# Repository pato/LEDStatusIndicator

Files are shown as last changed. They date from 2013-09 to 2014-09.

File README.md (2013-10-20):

LEDStatusIndicator
==================

Handy device that you can use to inform people outside your dorm on whether you are available, working, sleeping, or in need of solitude

First Protype
-------------
The first prototype was just a breadboard with four LEDs. There was no way of changing color besides manually using a jump cable to power them.
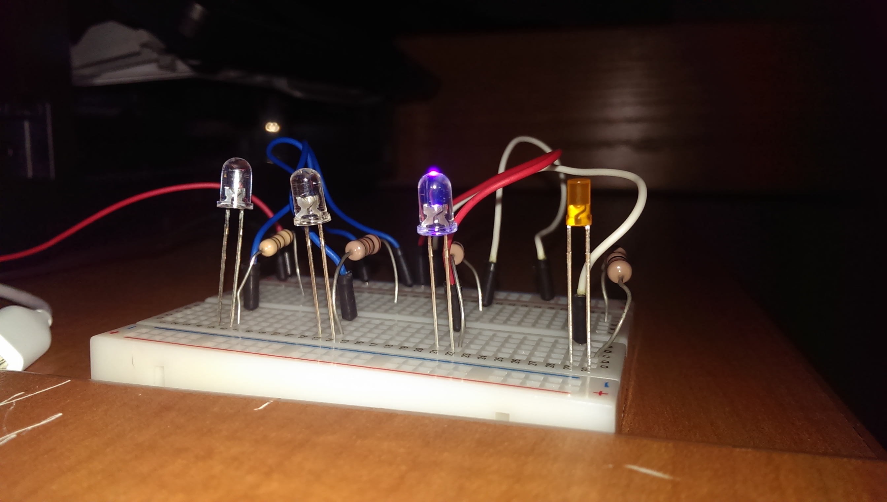
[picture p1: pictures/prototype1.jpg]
first prototype


Second Protype
--------------
The second prototype did not use a breadboard, instead I soldered the cables to the resistors to the LEDs. The anodes are all soldered together and the cathod so the LEDs are toggled by manually providing power to the desired LED.
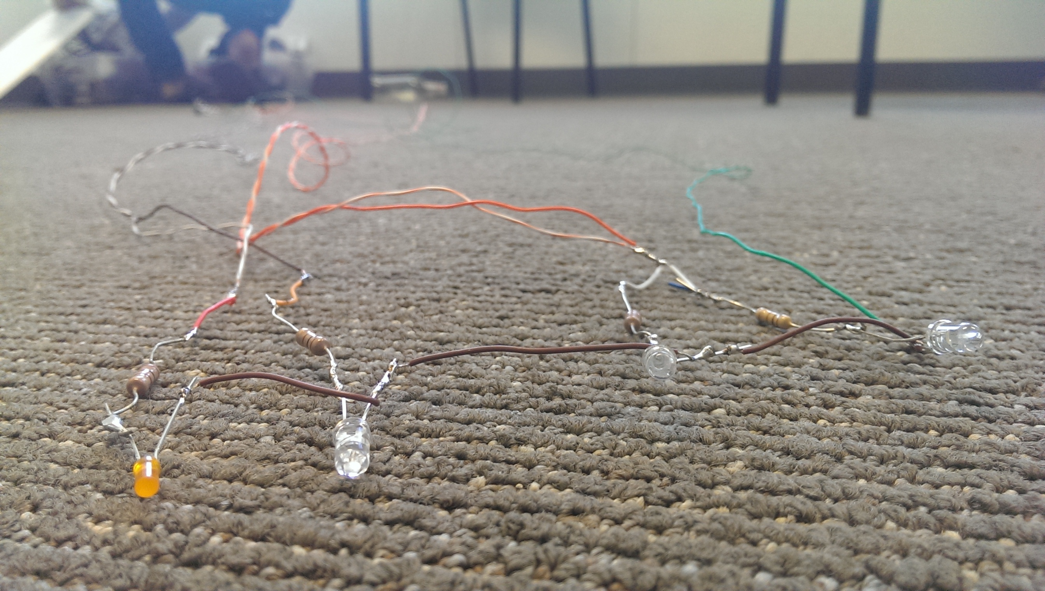
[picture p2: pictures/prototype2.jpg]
second prototype


Third Prototype
---------------
The third prototype was housed in a cardboard box, the cables to power the LEDs would go over and around the door to the inside of the room where I could control which lights turn on.
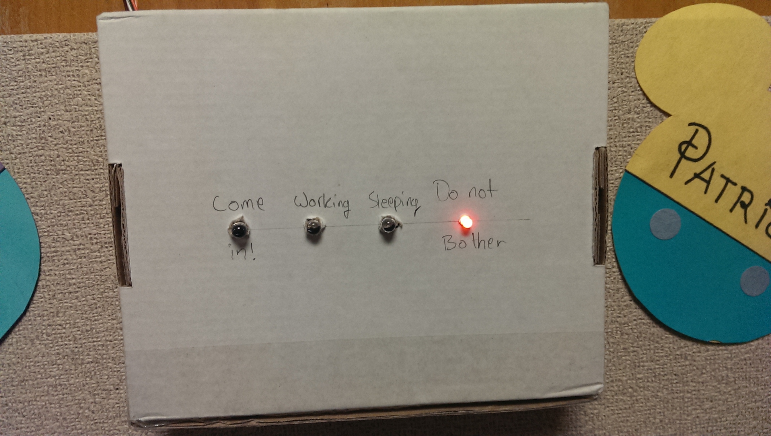
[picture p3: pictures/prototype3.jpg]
third prototype


Fourth Prototype
----------------
The fourth prototype uses an ATMega168, a push button, and an RGB LED. The button iterates through the various preset colors on the LED.
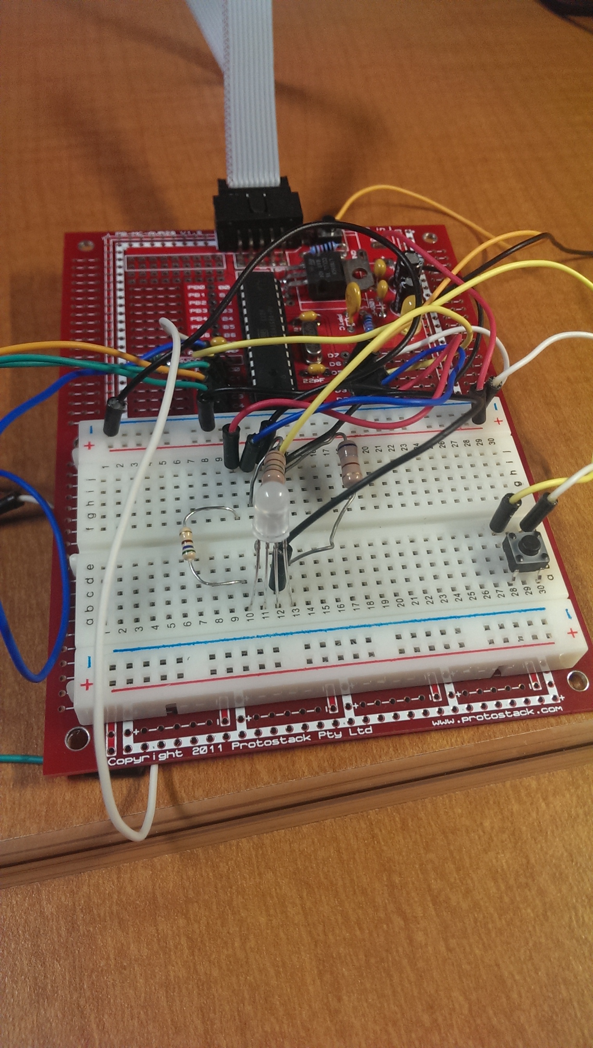
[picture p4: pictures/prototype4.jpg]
fourth prototype

This is how it looks on the other side of the door.
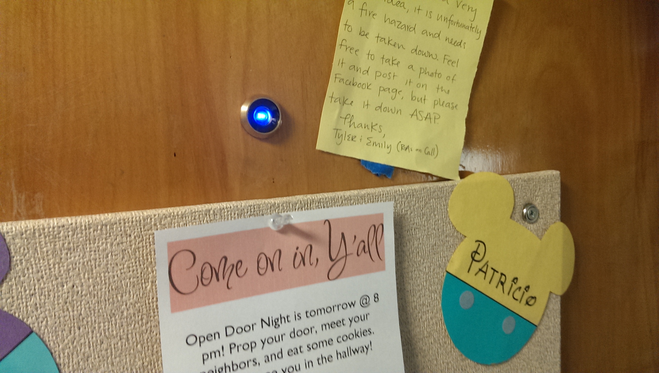
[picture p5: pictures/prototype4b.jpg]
fourth prototype


Fifth Prototype
---------------
The goal of the fifth protype was to reduce parts, size, and costs, as well as make it battery powered. We used an ATTiny45, a capacitor, four resistors, a push button, jumper cables, and RGB LED.
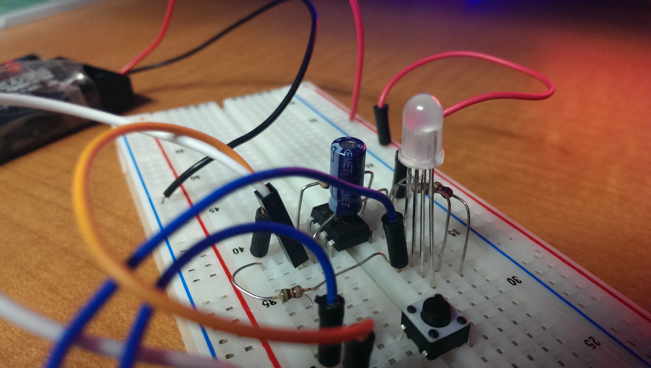
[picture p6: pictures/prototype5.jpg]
fifth prototype

In order to make it battery powered, we drastically reduced the frequence of the internal oscillator as well as made the LED pulse at interval instead of constnatly on.

First Beta
----------
The PCB boards from our friends at Oshpark! (PS: They're awesome!)
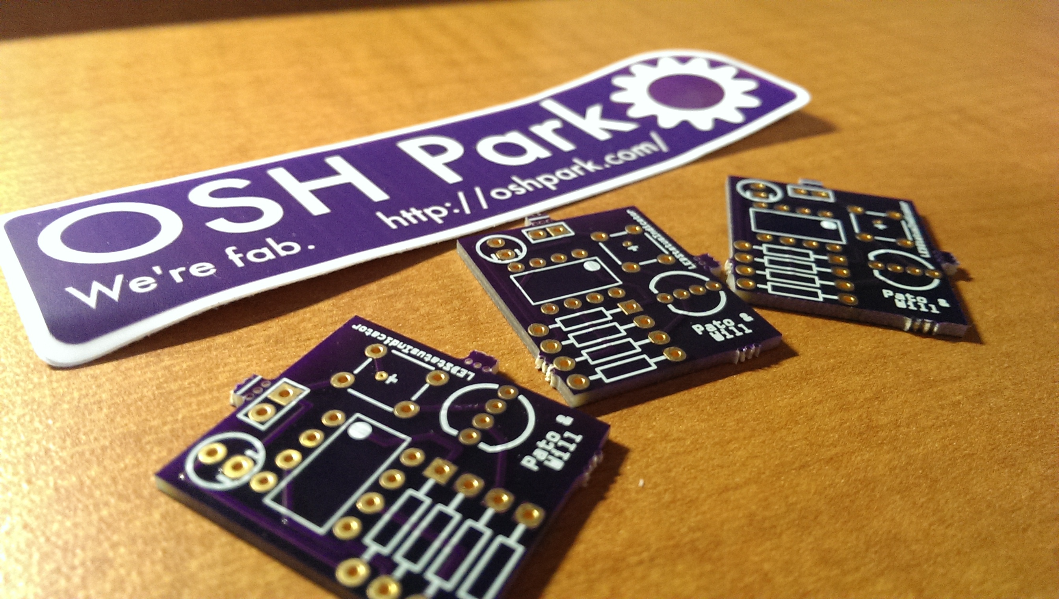
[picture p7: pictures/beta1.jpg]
first beta


From the backside
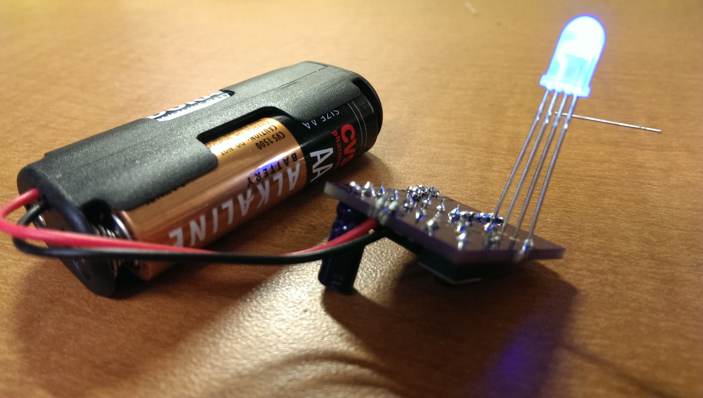
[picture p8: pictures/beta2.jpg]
first beta


From the front side
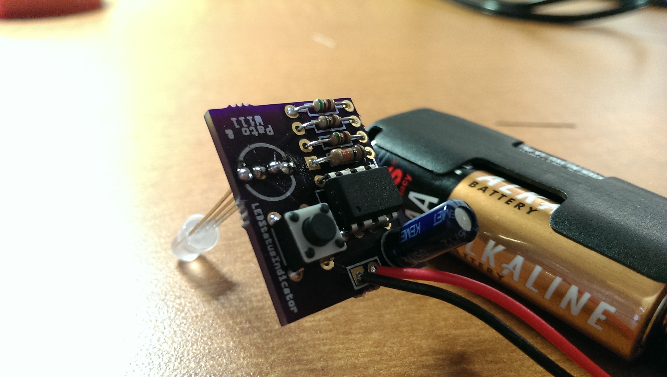
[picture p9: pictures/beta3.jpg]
first beta


Here's how it looks mounted on the door!
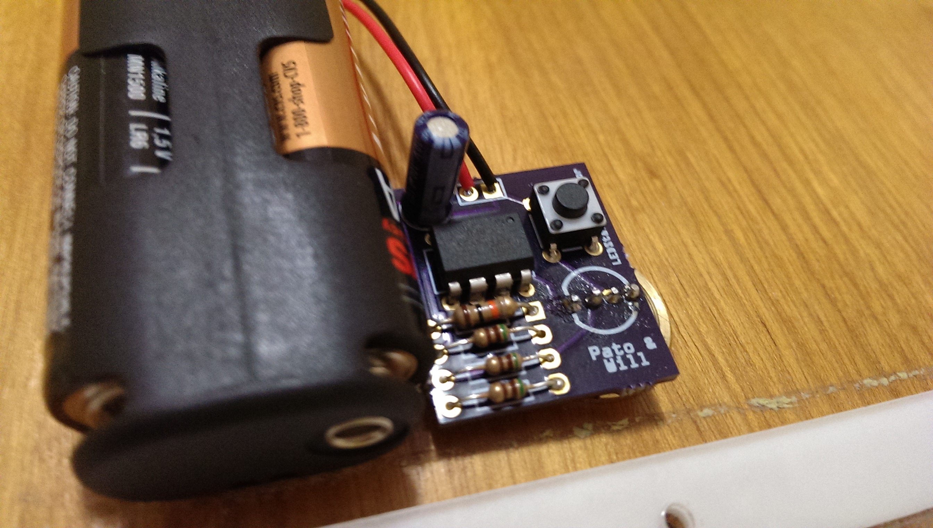
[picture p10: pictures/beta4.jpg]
first beta


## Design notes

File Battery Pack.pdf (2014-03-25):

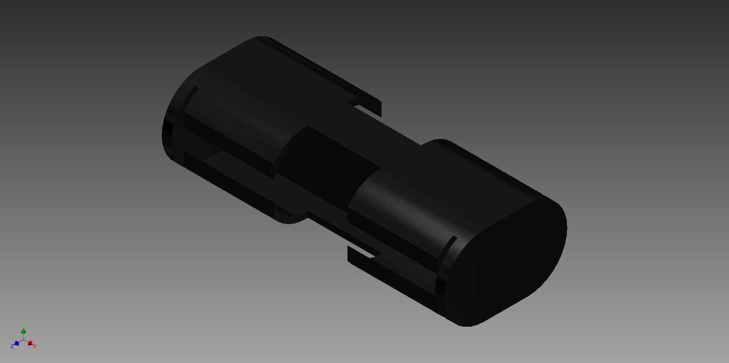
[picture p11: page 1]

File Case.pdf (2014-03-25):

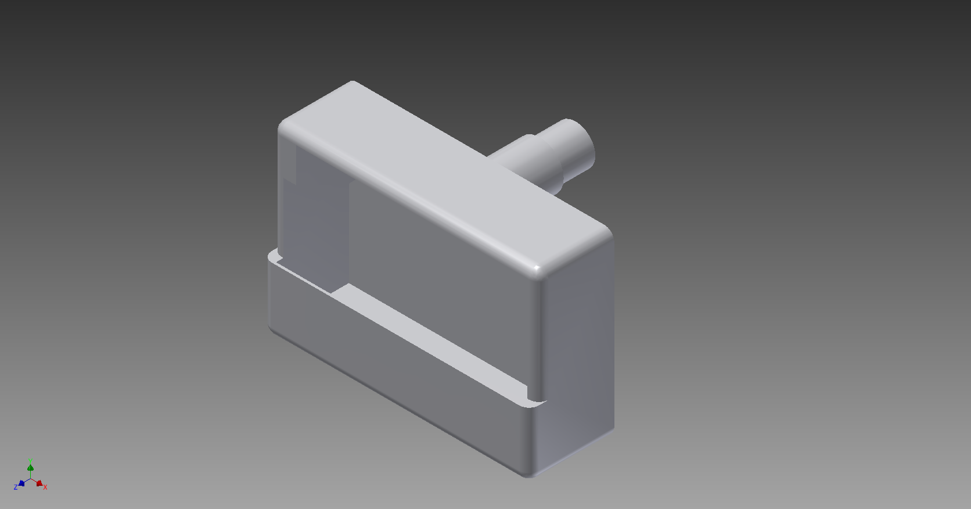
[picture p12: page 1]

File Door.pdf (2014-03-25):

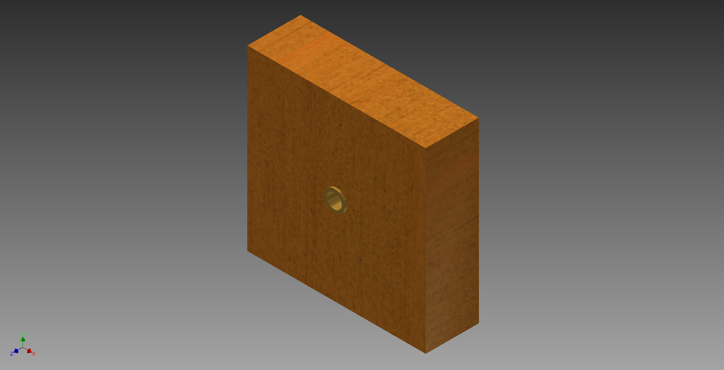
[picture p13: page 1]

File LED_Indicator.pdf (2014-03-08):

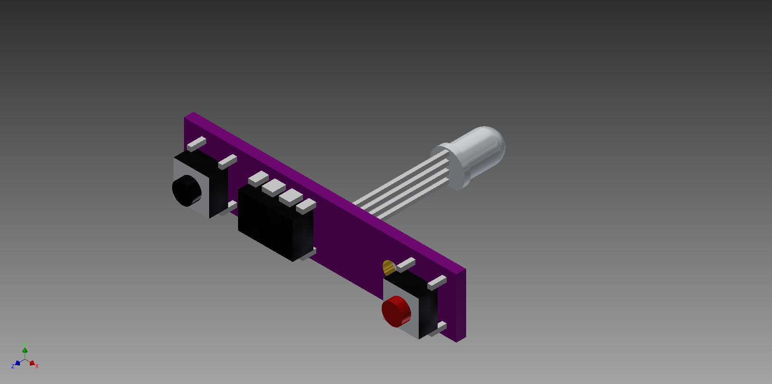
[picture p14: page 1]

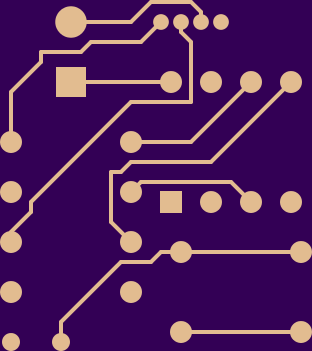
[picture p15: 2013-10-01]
PCB/render/large_i4.png

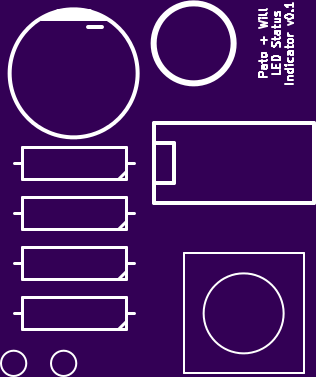
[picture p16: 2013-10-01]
PCB/render/large_i7.png

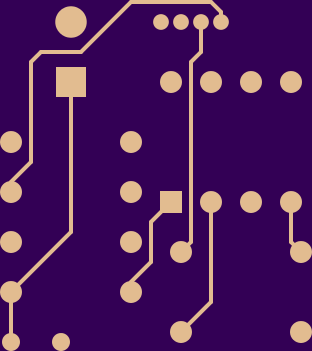
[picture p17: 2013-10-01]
PCB/render/large_i6.png

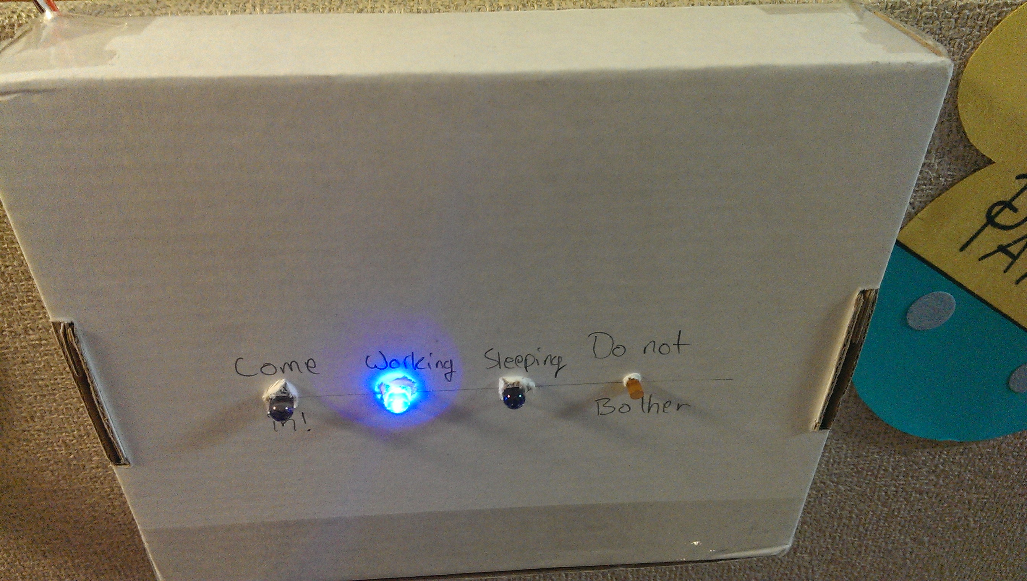
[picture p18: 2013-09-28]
pictures/prototype3b.jpg

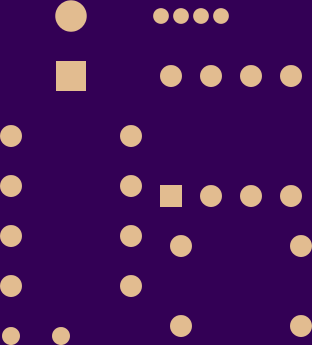
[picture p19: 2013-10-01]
PCB/render/large_i5.png

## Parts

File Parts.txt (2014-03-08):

attiny25                ATTINY25-20PU-ND        1.05 to .66 (25)        x1
resistor (reset)        S11KQCT-ND              .08-.055(10)            x1

button                  450-1650-ND             .1-.09(10)              x1
button                  450-1804-ND             .1-.92(10)              x1

3 resistors             S510QCT-ND              .08-.055(10)            x3
RGB xCxx LED            754-1615-ND             1.89-1.06               x1

battery holder          BC22AAW-ND              .92-.855(10)            x1

1.05+.08+.15+.1+.08+1.89+.54=3.89

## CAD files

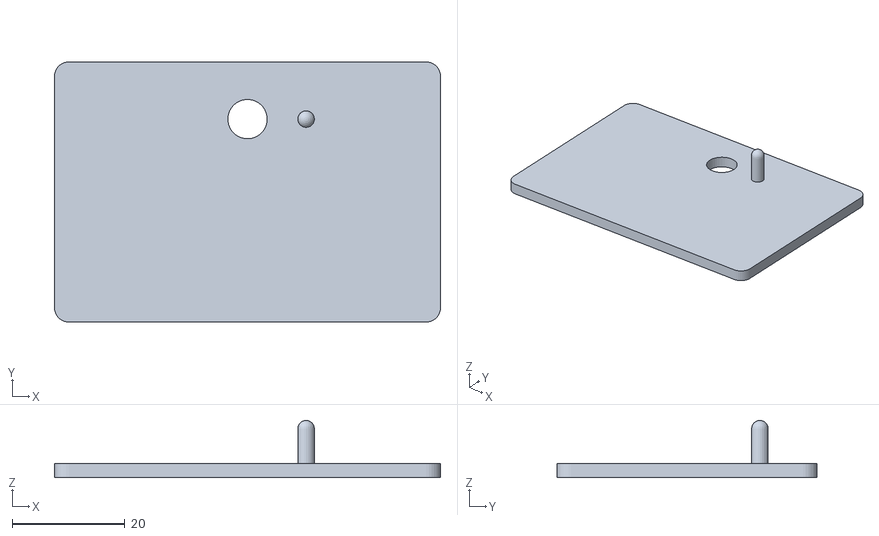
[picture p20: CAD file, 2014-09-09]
Front_Plate.stl
68.6 x 46.2 x 10.2

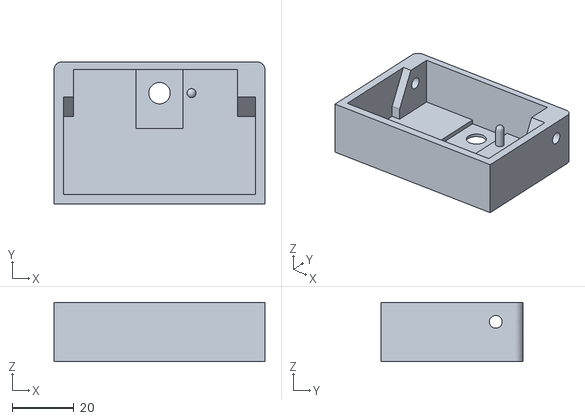
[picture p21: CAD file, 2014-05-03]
Case_Cutout.stl
68.6 x 46.2 x 19.3

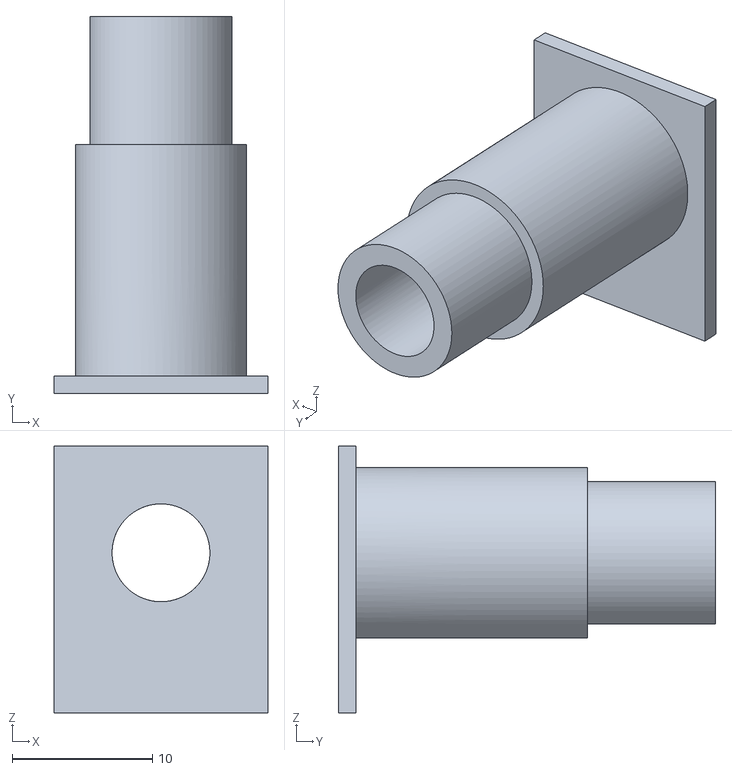
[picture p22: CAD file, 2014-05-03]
Tube_Part.stl
15.2 x 26.9 x 19.1

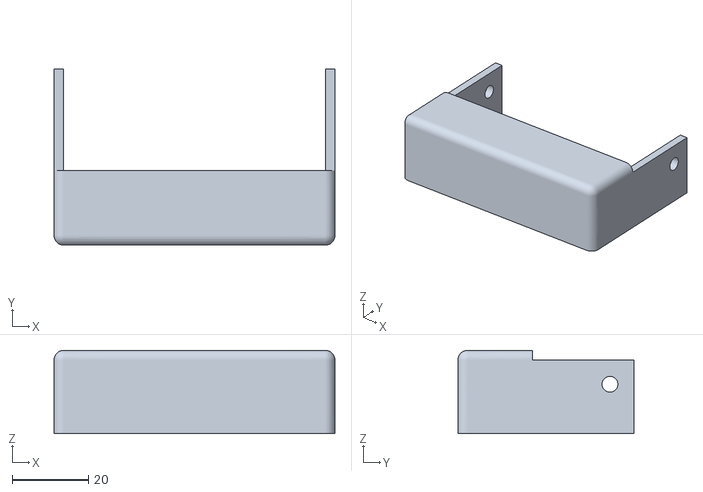
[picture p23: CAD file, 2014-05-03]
Back_Shield.stl
73.7 x 46.2 x 21.8

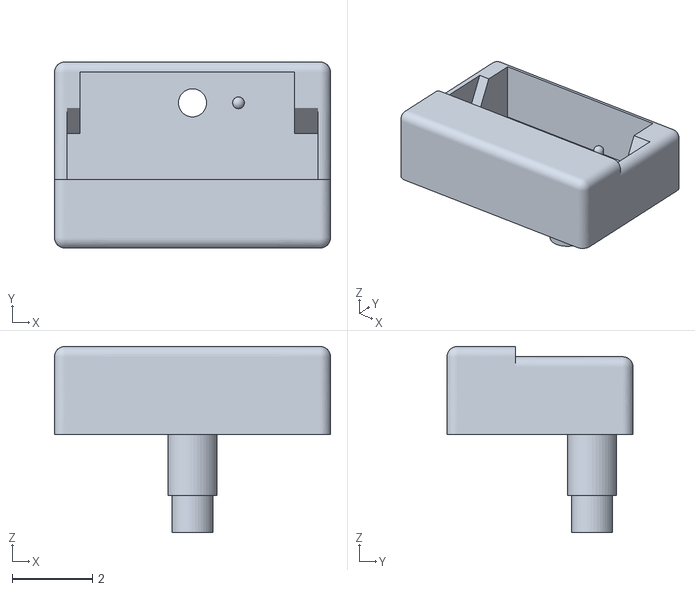
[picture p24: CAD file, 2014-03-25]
Case.stl
6.86 x 4.62 x 4.62

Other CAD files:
Assembly.iam
Back_Shield.ipt
Battery Pack.ipt
Case.ipt
Case_Cutout.ipt
Door.ipt
Front_Plate.ipt
LED Indicator.ipt
Tube_Part.ipt

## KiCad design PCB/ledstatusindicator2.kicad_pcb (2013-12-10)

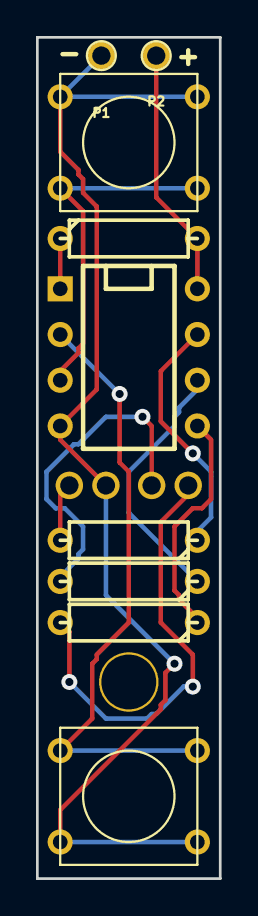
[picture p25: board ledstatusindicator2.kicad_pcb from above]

Board: 2 copper layers, 10.2 x 46.7 mm, 11 parts (1 on the bottom side), 11 nets.

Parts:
1PIN: P***; 1pin
IC1: ATTINY25-P; DIP-8__300
LED1: LED_RCBG; LED5_RGB
P1, P2: CONN_1; PINTST
R1, R2, R3, R4: R; R3
SW1, SW2: SW_PUSH; SW_PUSH_SMALL

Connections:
GND: IC1.4, LED1.2, P1.1, SW1.1, SW2.1
unnamed: LED1.1, R1.2
unnamed: IC1.8, P2.1, R4.2
unnamed: IC1.2, SW1.2
unnamed: LED1.3, R2.2
unnamed: LED1.4, R3.2
unnamed: IC1.3, SW2.2
unnamed: IC1.7, R1.1
unnamed: IC1.5, R3.1
unnamed: IC1.6, R2.1
unnamed: IC1.1, R4.1

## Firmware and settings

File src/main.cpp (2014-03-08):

extern "C"{
#include <avr/io.h>
#include <util/delay.h>
#include <avr/pgmspace.h>
#include <inttypes.h>
#include <avr/interrupt.h>
#include <avr/power.h>
#include <avr/sleep.h>
}


//Sine wave
//uint8_t led_pulse_curve[] = { 0, 2, 4, 6, 8, 10, 11, 13, 15, 17, 19, 21, 23, 25, 27, 29, 30, 32, 34, 35, 37, 39, 40, 42, 43, 45, 46, 48, 49, 50, 51, 52, 54, 55, 56, 57, 57, 58, 59, 60, 60, 61, 61, 62, 62, 63, 63, 63, 63, 63, 64, 63, 63, 63, 63, 63, 62, 62, 61, 61, 60, 60, 59, 58, 57, 57, 56, 55, 54, 52, 51, 50, 49, 48, 46, 45, 43, 42, 40, 39, 37, 35, 34, 32, 30, 29, 27, 25, 23, 21, 19, 17, 15, 13, 11, 10, 8, 6, 4, 2, 0};
//Modified sine wave
uint8_t led_pulse_curve[] = { 0, 0, 0, 0, 1, 1, 2, 3, 3, 4, 6, 7, 8, 10, 11, 13, 14, 16, 18, 20, 22, 24, 26, 27, 29, 32, 34, 36, 37, 39, 41, 43, 45, 47, 49, 50, 52, 53, 55, 56, 57, 59, 60, 60, 61, 62, 62, 63, 63, 63, 64, 63, 63, 63, 62, 62, 61, 60, 60, 59, 57, 56, 55, 53, 52, 50, 49, 47, 45, 43, 41, 39, 37, 36, 34, 32, 29, 27, 26, 24, 22, 20, 18, 16, 14, 13, 11, 10, 8, 7, 6, 4, 3, 3, 2, 1, 1, 0, 0, 0, 0};

const uint8_t green = 1 << 0;
const uint8_t blue = 1 << 1;
const uint8_t red = 1 << 2;
const uint8_t sw1 = 1 << 3;
const uint8_t sw2 = 1 << 4;
//All the possible LED colors. 0-3 are accessed with one button, and 4 is accessed with the other button.
const uint8_t led_colors[] = {0, green, blue, red};//PCB

volatile uint8_t current_color; //Changed by interrupt
volatile bool interrupt_has_occurred; //Set to true inside any interrupts

//Does a software PWM. The LEDs you want to blink should be set to 1 in mask
//And the duty cycle is out of 64
void softPWM(const uint8_t duty, const uint8_t mask){
    PORTB |= mask;
    for (int i = 0; i < duty; ++i)
    {
        asm volatile("nop");
        //_delay_us(150);
    }
    PORTB &= ~mask;
    for (int i = duty; i < 64; ++i)
    {
        asm volatile("nop");
        //_delay_us(150);
    }
}

//Cycle through the brightnesses specified in led_pulse_curve
void pwm_ramp(const uint8_t mask){
    if(mask == 0) return;
    for (uint8_t i = 0; i < sizeof(led_pulse_curve); ++i)
    {
        if(interrupt_has_occurred) return;
        softPWM(led_pulse_curve[i], mask);
    } 
}

//Triggers the WDT_vect interrupt every 2 seconds. Used to wake from sleep mode.
void enable_watchdog_interrupt(){
	//Set WDIE //Enable watchdog timer interrupt
	//For the prescaler:
    //WDP3 = 4 second timeout
    //WDP0,1,2 = 2 second timeout
    
    WDTCR = (1<<WDIE) | (1<<WDP2) | (1<<WDP1) | (1<<WDP0);
    
}

//Sets watchdog timer back to 0
void reset_watchdog(){
	asm volatile("wdr");
}

SIGNAL(SIG_PIN_CHANGE){
    // //Normal clock mode. Clock /= 8
    // CLKPR = (1<<CLKPCE);
    // CLKPR = (1<<CLKPS0)||(1<<CLKPS1);
    bool button1 = PINB & sw1; //State of button
    bool button2 = PINB & sw2;
    if (button1 == false)//Button 1 has been pushed. Goes to red mode
    {
        _delay_ms(20);
        button1 = PINB & sw1;
        if(button1 == false){ //And it wasn't just bouncing
            reset_watchdog();
            current_color = 3; //Turn on the red
            interrupt_has_occurred = true;
        }
    }
    else if (button2 == false)//Button 2 has been pushed. Cycle through non-red modes.
    {
        _delay_ms(20);
        button2 = PINB & sw2;
        if(button2 == false){ //And it wasn't just bouncing
            reset_watchdog();
            current_color++;
            if(current_color >= 3) current_color = 0;
            interrupt_has_occurred = true;
        }
    }
    
}

ISR(WDT_vect){
	interrupt_has_occurred = true;
}


//Sleeps the microcontroller. Wakes up on interrupt (button or watchdog overflow)
void go_to_sleep(){
    //MCUCR:
        //Set SE //Enable sleep mode
        //Set SM[1:0] to 0b10 //Choose deep sleep mode
    //Call SLEEP instruction
    MCUCR |= (1<<SE) | (1<<SM1);
    asm volatile("sleep");
}

int main(void)
{
    current_color = 0;

    DDRB = red | green | blue; //Set LEDs to output

    PORTB = sw1 | sw2;//Pullup resistor for buttons

    _delay_ms(1);//Wait for pullup to work

    GIMSK |= (1<<PCIE);//Enable pin interrupts
    PCMSK |= (1<<PCINT3) | (1<<PCINT4);//Allow an interrupt from the buttons (pins 3 and 4)
    sei();//Enable interrupts
    
    //Super low power time
    power_all_disable(); //Disable all unused peripherals (including ADC)
    ACSR &= ~(1<<ACD);//Turn off analog comparator (not ADC)


    //Set clock frequency to watchdog/8
    CLKPR = (1<<CLKPCE);
    CLKPR = (1<<CLKPS0)||(1<<CLKPS1);

    //Every 2 seconds, the watchdog timer will overflow and trigger an interupt
    enable_watchdog_interrupt();

    for(;;){
        interrupt_has_occurred = false;
        pwm_ramp(led_colors[current_color]);
        PORTB &= ~(red|green|blue);//Turn off all LEDs, just in case

        reset_watchdog(); //Watchdog interrupt will be triggered in 2 seconds *from now*
        //If an interrupt occurred since we set this to false, it means someone has pushed
        // a button and we should go to the next color.
        if(!interrupt_has_occurred){
            go_to_sleep();
        }
    }

    return 0;
}

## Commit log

2013-09-22 Added first board design
    [noname.brd, noname.sch]
2013-09-24 used watchdog timer
2013-09-28 Did a bunch of LED stuff
    [noname.brd]
2013-09-28 doing led stuff
2013-09-30 update added PCB
    [LEDStatusIndicator.fzz, LEDStatusIndicatorSmall.fzz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]
2013-09-30 added small version
    [LEDStatusIndicatorSmall.fzz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]
2013-09-30 Messed with led programming
2013-09-30 Added Will's PCB
    [LEDStatusIndicator.fzz, LEDStatusIndicatorSmall.fzz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]
2013-10-01 using software pwm
2013-10-01 working software PWM and button interrupt
2013-10-01 pcb files
    [LEDStatusIndicatorSmall.fzz, LEDStatusIndicatorSmallHoles.fzz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]
2013-10-01 added fifth prototype
2013-10-05 editing LED stuff
2013-10-06 Super duper power efficient (4.5uA idle)
    [ledstatus.kicad_pcb]
2013-10-22 Decreased power consumption and fixed debouncing
    [main.cpp]
2013-11-01 New PCBs
    [ledstatus-B_Cu.gbl, ledstatus-B_Mask.gbs, ledstatus-B_SilkS.gbo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]
2013-12-29 Removed old PCBs again
    [LEDStatusIndicator.fzz, LEDStatusIndicatorSmall.fzz, LEDStatusIndicatorSmallHoles.fzz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]
2013-12-29 Changed PCB folder name
    [ledstatus-B_Cu.gbl, ledstatus-B_Mask.gbs, ledstatus-B_SilkS.gbo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]
2013-12-29 Re-named a bunch of stuff
    [ledstatusindicator2.kicad_pcb, ledstatusindicator2.sch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]
2013-12-29 Updated schematic
2013-12-29 Updated firmware for new PCB
2013-12-29 Added watchdog reset in pin change interrupt
    [main.cpp]
2014-01-04 cleaned gerber files
2014-02-03 Added rendered images of the top and bottom PCB layers
2014-02-14 Updated parts.txt with new reset resistor
2014-03-08 Added CAD PDF File
    Exactly what it says on the tin.
2014-03-23 Added the initial prototype 3D modeling files. I also included the .stl file for the case, incase it is needed.
    [Battery Pack.ipt, Case.ipt, Case.stl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]
2014-04-12 Fixed .stl units
    [Case.stl]
2014-05-02 Added new separte part files and respective .stl files
    [Assembly.iam, Back_Shield.ipt, Back_Shield.stl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]
2014-09-08 Added new Plate design (Front_Plate)
    [Front_Plate.ipt, Front_Plate.stl]
